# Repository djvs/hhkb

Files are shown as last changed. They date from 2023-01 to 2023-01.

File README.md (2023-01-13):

# hhkb

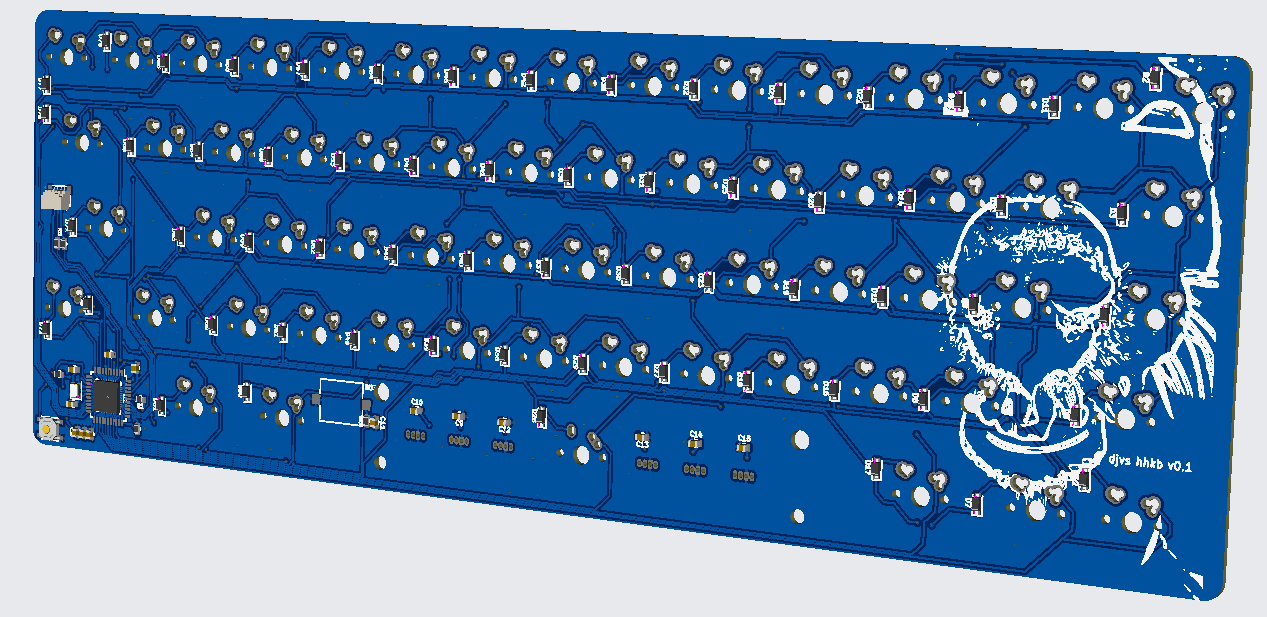
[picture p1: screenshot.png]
Screenshot of PCB


USB/QMK atmega32u4 pcb for HHKB with WS2812B addressable LED support and sonalert buzzer.  

Released without warranty, use at your own risk.  

PRs & feedback welcome!

---

Dimensions: 285 x 100 mm

---

Shield: [][cc-by-sa]

This work is licensed under a
[Creative Commons Attribution-ShareAlike 4.0 International License][cc-by-sa].

[][cc-by-sa]

[cc-by-sa]: http://creativecommons.org/licenses/by-sa/4.0/
[cc-by-sa-image]: https://licensebuttons.net/l/by-sa/4.0/88x31.png
[cc-by-sa-shield]: https://img.shields.io/badge/License-CC%20BY--SA%204.0-lightgrey.svg

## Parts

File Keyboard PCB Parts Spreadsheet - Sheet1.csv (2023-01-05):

Part Name | Part Type | Value | Footprint | Digikey Part Num. | LCSC Part Num. | JLCSMT Type | Other Notes
nSMD050-24V | PTC Resettable Fuse | 500mA | 1206 |  | C70076 | Extended
1206L050/15YR | Polyfuse | 500mA Hold / 1A Trip | 1206 |  | C151162 | Extended | The fuse listed in the tutorial doesn't appear to be available, but this one is.
0603WAF220JT5E | Resistor | 22 | 0603 |  | C23345 | Basic
0603WAF1001T5E | Resistor | 1k | 0603 |  | C21191 | Basic
0603WAF5101T5E | Resistor | 5.1k | 0603 |  | C23186 | Basic
0603WAF1002T5E | Resistor | 10k | 0603 |  | C25804 | Basic
0603WAF3302T5E | Resistor | 33k | 0603 |  | C4216 | Basic
0603WAF1003T5E | Resistor | 100k | 0603 |  | C25803 | Basic
0603WAF1004T5E | Resistor | 1M | 0603 |  | C22935 | Basic
CL10C220JB8NNNC | Capacitor, Ceramic | 22pF | 0603 |  | C1653 | Basic
0603B472K500NT | Capacitor, Ceramic | 4.7nF | 0603 |  | C53987 | Basic
CC0603KRX7R9BB104 | Capacitor, Ceramic | 0.1uF | 0603 |  | C14663 | Basic
CL10A105KB8NNNC | Capacitor, Ceramic | 1uF | 0603 |  | C15849 | Basic
CL10A475KO8NNNC | Capacitor, Ceramic | 4.7uF | 0603 |  | C19666 | Basic
CL10A106KP8NNNC | Capacitor, Ceramic | 10uF | 0603 |  | C19702 | Basic
CL10A226MQ8NRNC | Capacitor, Ceramic | 22uF | 0603 |  | C59461 | Basic
0603WAF4701T5E | Resistor | 4.7k | 0603 |  | C23162 | Basic
0805W8F220JT5E | Resistor | 22 | 0805 |  | C17561 | Basic
0805W8F1001T5E | Resistor | 1k | 0805 |  | C17513 | Basic
0805W8F5101T5E | Resistor | 5.1k | 0805 |  | C27834 | Basic
0805W8F1002T5E | Resistor | 10k | 0805 |  | C17414 | Basic
0805W8F3302T5E | Resistor | 33k | 0805 |  | C17633 | Basic
0805W8F1003T5E | Resistor | 100k | 0805 |  | C17407 | Basic
0805W8F1004T5E | Resistor | 1M | 0805 |  | C17514 | Basic
CL21C220JBANNNC | Capacitor, Ceramic | 22pF | 0805 |  | C1804 | Basic
0805B472K500NT | Capacitor, Ceramic | 4.7nF | 0805 |  | C1744 | Basic
CC0805KRX7R9BB104 | Capacitor, Ceramic | 0.1uF | 0805 |  | C49678 | Basic
CL21B105KBFNNNE | Capacitor, Ceramic | 1uF | 0805 |  | C28323 | Basic
CL21A475KAQNNNE | Capacitor, Ceramic | 4.7uF | 0805 |  | C1779 | Basic
CL21A106KAYNNNE | Capacitor, Ceramic | 10uF | 0805 |  | C15850 | Basic
CL21A226MAQNNNE | Capacitor, Ceramic | 22uF | 0805 |  | C45783 | Basic
0805W8F4701T5E | Resistor | 4.7k | 0805 |  | C17673 | Basic | Used by split boards w/ QMK
PJ-320A | TRRS Connector, 3.5mm, THT |  | 3.5-4P |  | --- | Unavailable | Many colors available on Taobao
ATMEGA32U2-AU | Microcontroller | AVR | 32-TQFP (7x7) | ATMEGA32U2-AU-ND | C618733 | Unavailable
ATMEGA32U2-MU | Microcontroller | AVR | 32-VQFN (5x5) | ATMEGA32U2-MU-ND | C57345 | Extended
X322516MLB4SI | Crystal Oscillator | 16MHz | 3225 |  | C13738 | Basic
TS-1186D-C-A | Push Button |  | 4.70mm x 3.50mm |  | C397351 | Unavailable | Side-actuated tactile switch
ATMEGA32U4-AU | Microcontroller | AVR | 44-TQFP (10x10) | ATMEGA32U4-AU-ND | C44854 | Extended
ATMEGA32U4-MU | Microcontroller | AVR | 44-VQFN (7x7) | ATMEGA32U4-MU-ND | C112161 | Extended
STM32F072CBT6 | Microcontroller | ARM/STM32 | 48-LQFP (7x7) | 497-14645-ND | C81720 | Extended
STM32F072CBU6 | Microcontroller | ARM/STM32 | 48-UFQFPN (7x7) | 497-14646-ND | C92504 | Extended
TS-1187A-B-A-B | Push Button |  | 5.1 x 5.1 MM |  | C318884 | Extended
TAJB107K006RNJ | Capacitor, Tantalum | 100uF | CASE-B / 3528 |  | C16133 | Basic
EC11K1525413 | Encoder |  | EC11E |  | C470752 | Unavailable | "Best" normal encoder with detents
EC11E1834403 | Encoder |  | EC11E |  | C361165 | Unavailable | Highest pulse EC11E w/o detents, 1.5mm switch
EC11E15244B2 | Encoder |  | EC11E |  |  | Unavailable | 30 detent (highest reliable) EC11E, 1.5mm switch
TYPE-C-31-M-12 | USB-C |  | HRO-TYPE-C-31-M-12 |  | C165948 | Unavailable | Cheap popular easy to solder USB 2.0 USB-C connector, even cheaper clones available in bulk from aliexpress at around 15c/each, shipped, https://www.aliexpress.com/item/4000259156096.html
TYPE-C-31-M-13 | USB-C |  | HRO-TYPE-C-31-M-13 |  | C223906 | Unavailable | mid-mount version of M-12
TYPE-C-31-M-14 | USB-C |  | HRO-TYPE-C-31-M-14 |  | C223907 | Unavailable | Mid mount version USB-C - Used on the unsplit
DY-S352818/RGBC/6812-2T | LED |  | SK6812 Mini-E |  | C524051 | Unavailable | Tested and seems to work same as a SK6812 Mini-E
SM4007PL | Diode, Standard |  | SOD-123 |  | C64898 | Basic | cheapest diode on jlcpcb, price fluctuates but <$0.004 (at 200+) each
1N4148W | Diode, Standard |  | SOD-123 |  | C81598 | Basic | Common diode
RB060M-60 | Schottky Barrier Diode |  | SOD-123 |  | C115330 | Extended
SMF9.0CA | Bidirectional TVS Diode | 9V Breakdown | SOD-123 |  | C123799 | Extended
SMF6.0CA | Bidirectional TVS Diode | 6V Breakdown | SOD-123 |  | C123791 | Extended
UET14A05L03 | ESD Protection IC |  | SOT-143 |  | C78442 | Extended | Equivalent to PRTR5V0U2X but available as extended part for assembly
PRTR5V0U2X,215 | ESD Protection IC |  | SOT-143B | 1727-3884-2-ND | C12333 | Unavailable | USB data line ESD protection
XC6206P332MR | LDO | 3.3V | SOT-23 |  | C5446 | Basic | 3.3v 200mA LDO stable with ceramic caps and basic JLC part https://datasheet.lcsc.com/szlcsc/1809201513_Torex-Semicon-XC6206P332MR_C5446.pdf
DTC123JKAT146 | Transistor, NPN, Pre-Biased | DTC123J | SOT-23 |  | C111724 | Extended
AO3400A | MOSFET, N-Channel | 30V 5.7A | SOT-23 |  | C347475 | Extended
BSS138LT1G | MOSFET, N-Channel | 50V 200mA | SOT-23 |  | C82045 | Extended | Often used for level shifting
AO3400A | MOSFET, N-Channel | 30V 5.7A | SOT-23-3L |  | C20917 | Basic
SRV05-4-P-T7 | ESD Protection IC | 4 I/Os | SOT-23-6 |  | C85364 | Basic | basic part esd protection for usb https://datasheet.lcsc.com/szlcsc/1809192313_ProTek-Devices-SRV05-4-P-T7_C85364.pdf

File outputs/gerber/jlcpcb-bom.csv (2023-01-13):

Comment | Footprint | Designator | JLCPCB Part #（optional )
D_Small | D_SOD-123 | D16,D2,D3,D4,D5,D7,D8,D9,D10,D11,D13,D14,D15,D17,D18,D19,D20,D21,D24,D25,D26,D27,D28,D29,D30,D31,D32,D35,D36,D37,D38,D39,D40,D41,D42,D46,D47,D48,D49,D50,D51,D52,D53,D54,D57,D58,D59,D60,D61,D62,D63,D64,D65,D68,D69,D70,D71,D72,D76,D77,D12 | C81598
0.1uF | C_0805_2012Metric | C9,C1,C2,C5,C10,C12,C11,C14,C15,C13 | C49678
330 | R_0805_2012Metric | R1 | C17630
SW_Push | SKQG-1155865 | SW1 | C318884
1uF | C_0805_2012Metric | C6 | C28323
10uF | C_0805_2012Metric | C7 | C15850
Conn_01x04_MountingPin | JST_SH_SM04B-SRSS-TB_1x04-1MP_P1.00mm_Horizontal | J1 | C160404
10k | R_0805_2012Metric | R3,R4 | C17414
ATmega32U4-MU | atmega32u4-mu-and-au | U1 | C112161
16MHz | Crystal_SMD_3225-4Pin_3.2x2.5mm | Y1 | C13738
22pF | C_0805_2012Metric | C3,C4 | C1804
22 | R_0805_2012Metric | R5,R2,R6 | C17561

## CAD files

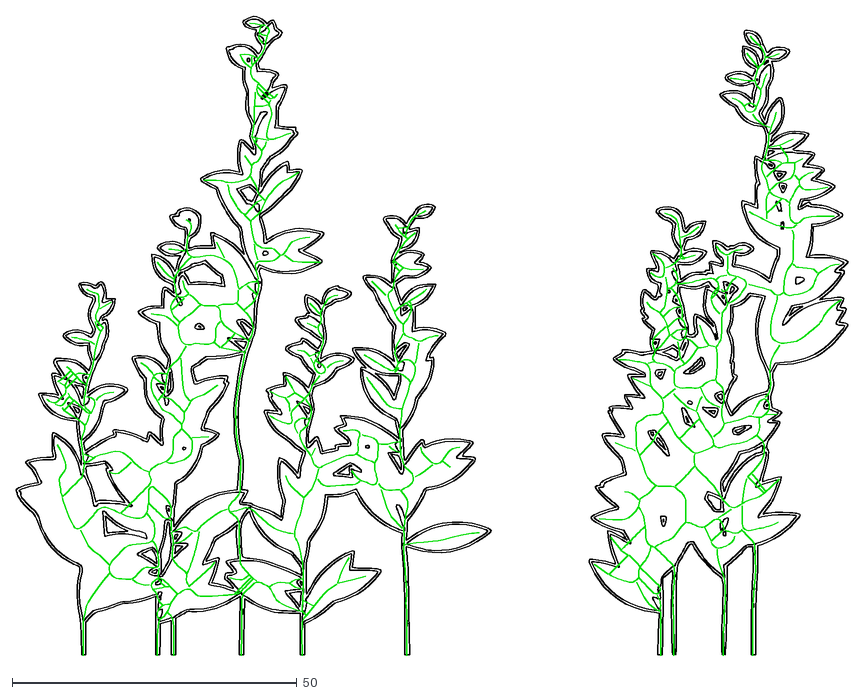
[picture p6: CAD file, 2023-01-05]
drawing.dxf
146.1 x 112.3

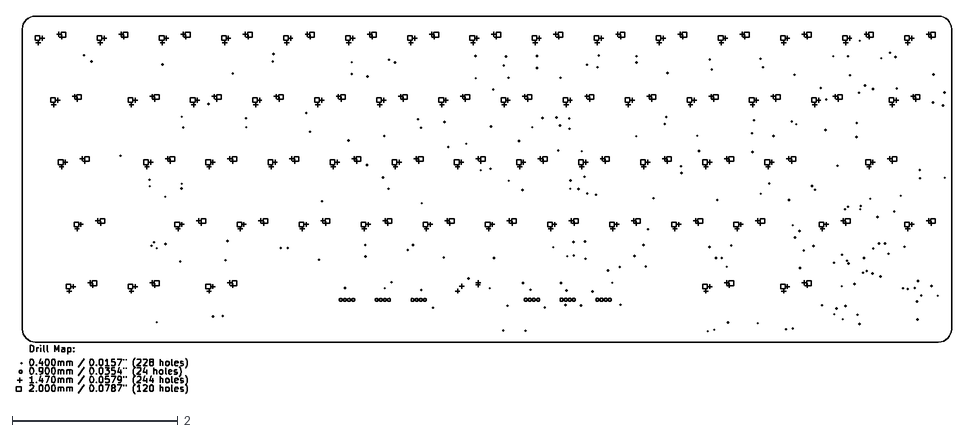
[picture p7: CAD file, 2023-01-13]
outputs/gerber/hhkb-PTH-drl_map.dxf
11.3 x 4.56

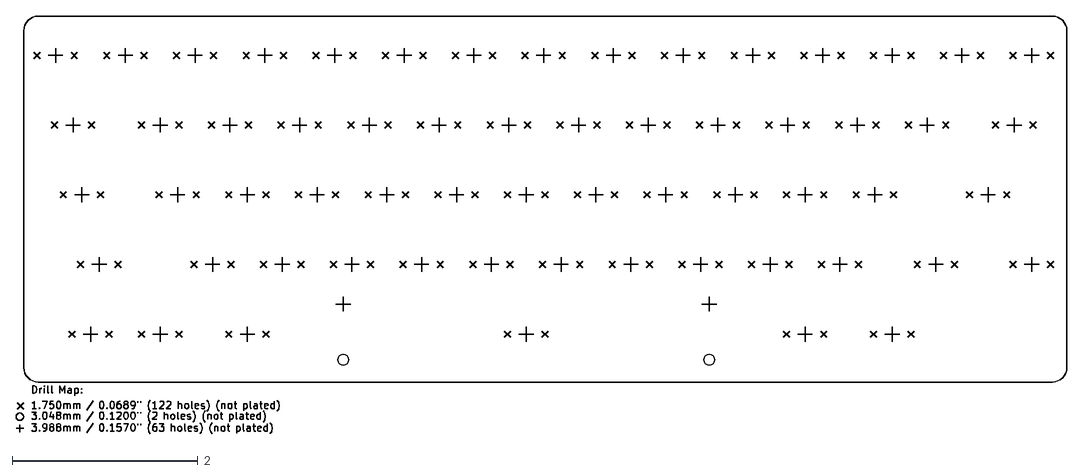
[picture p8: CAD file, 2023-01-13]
outputs/gerber/hhkb-NPTH-drl_map.dxf
11.3 x 4.49

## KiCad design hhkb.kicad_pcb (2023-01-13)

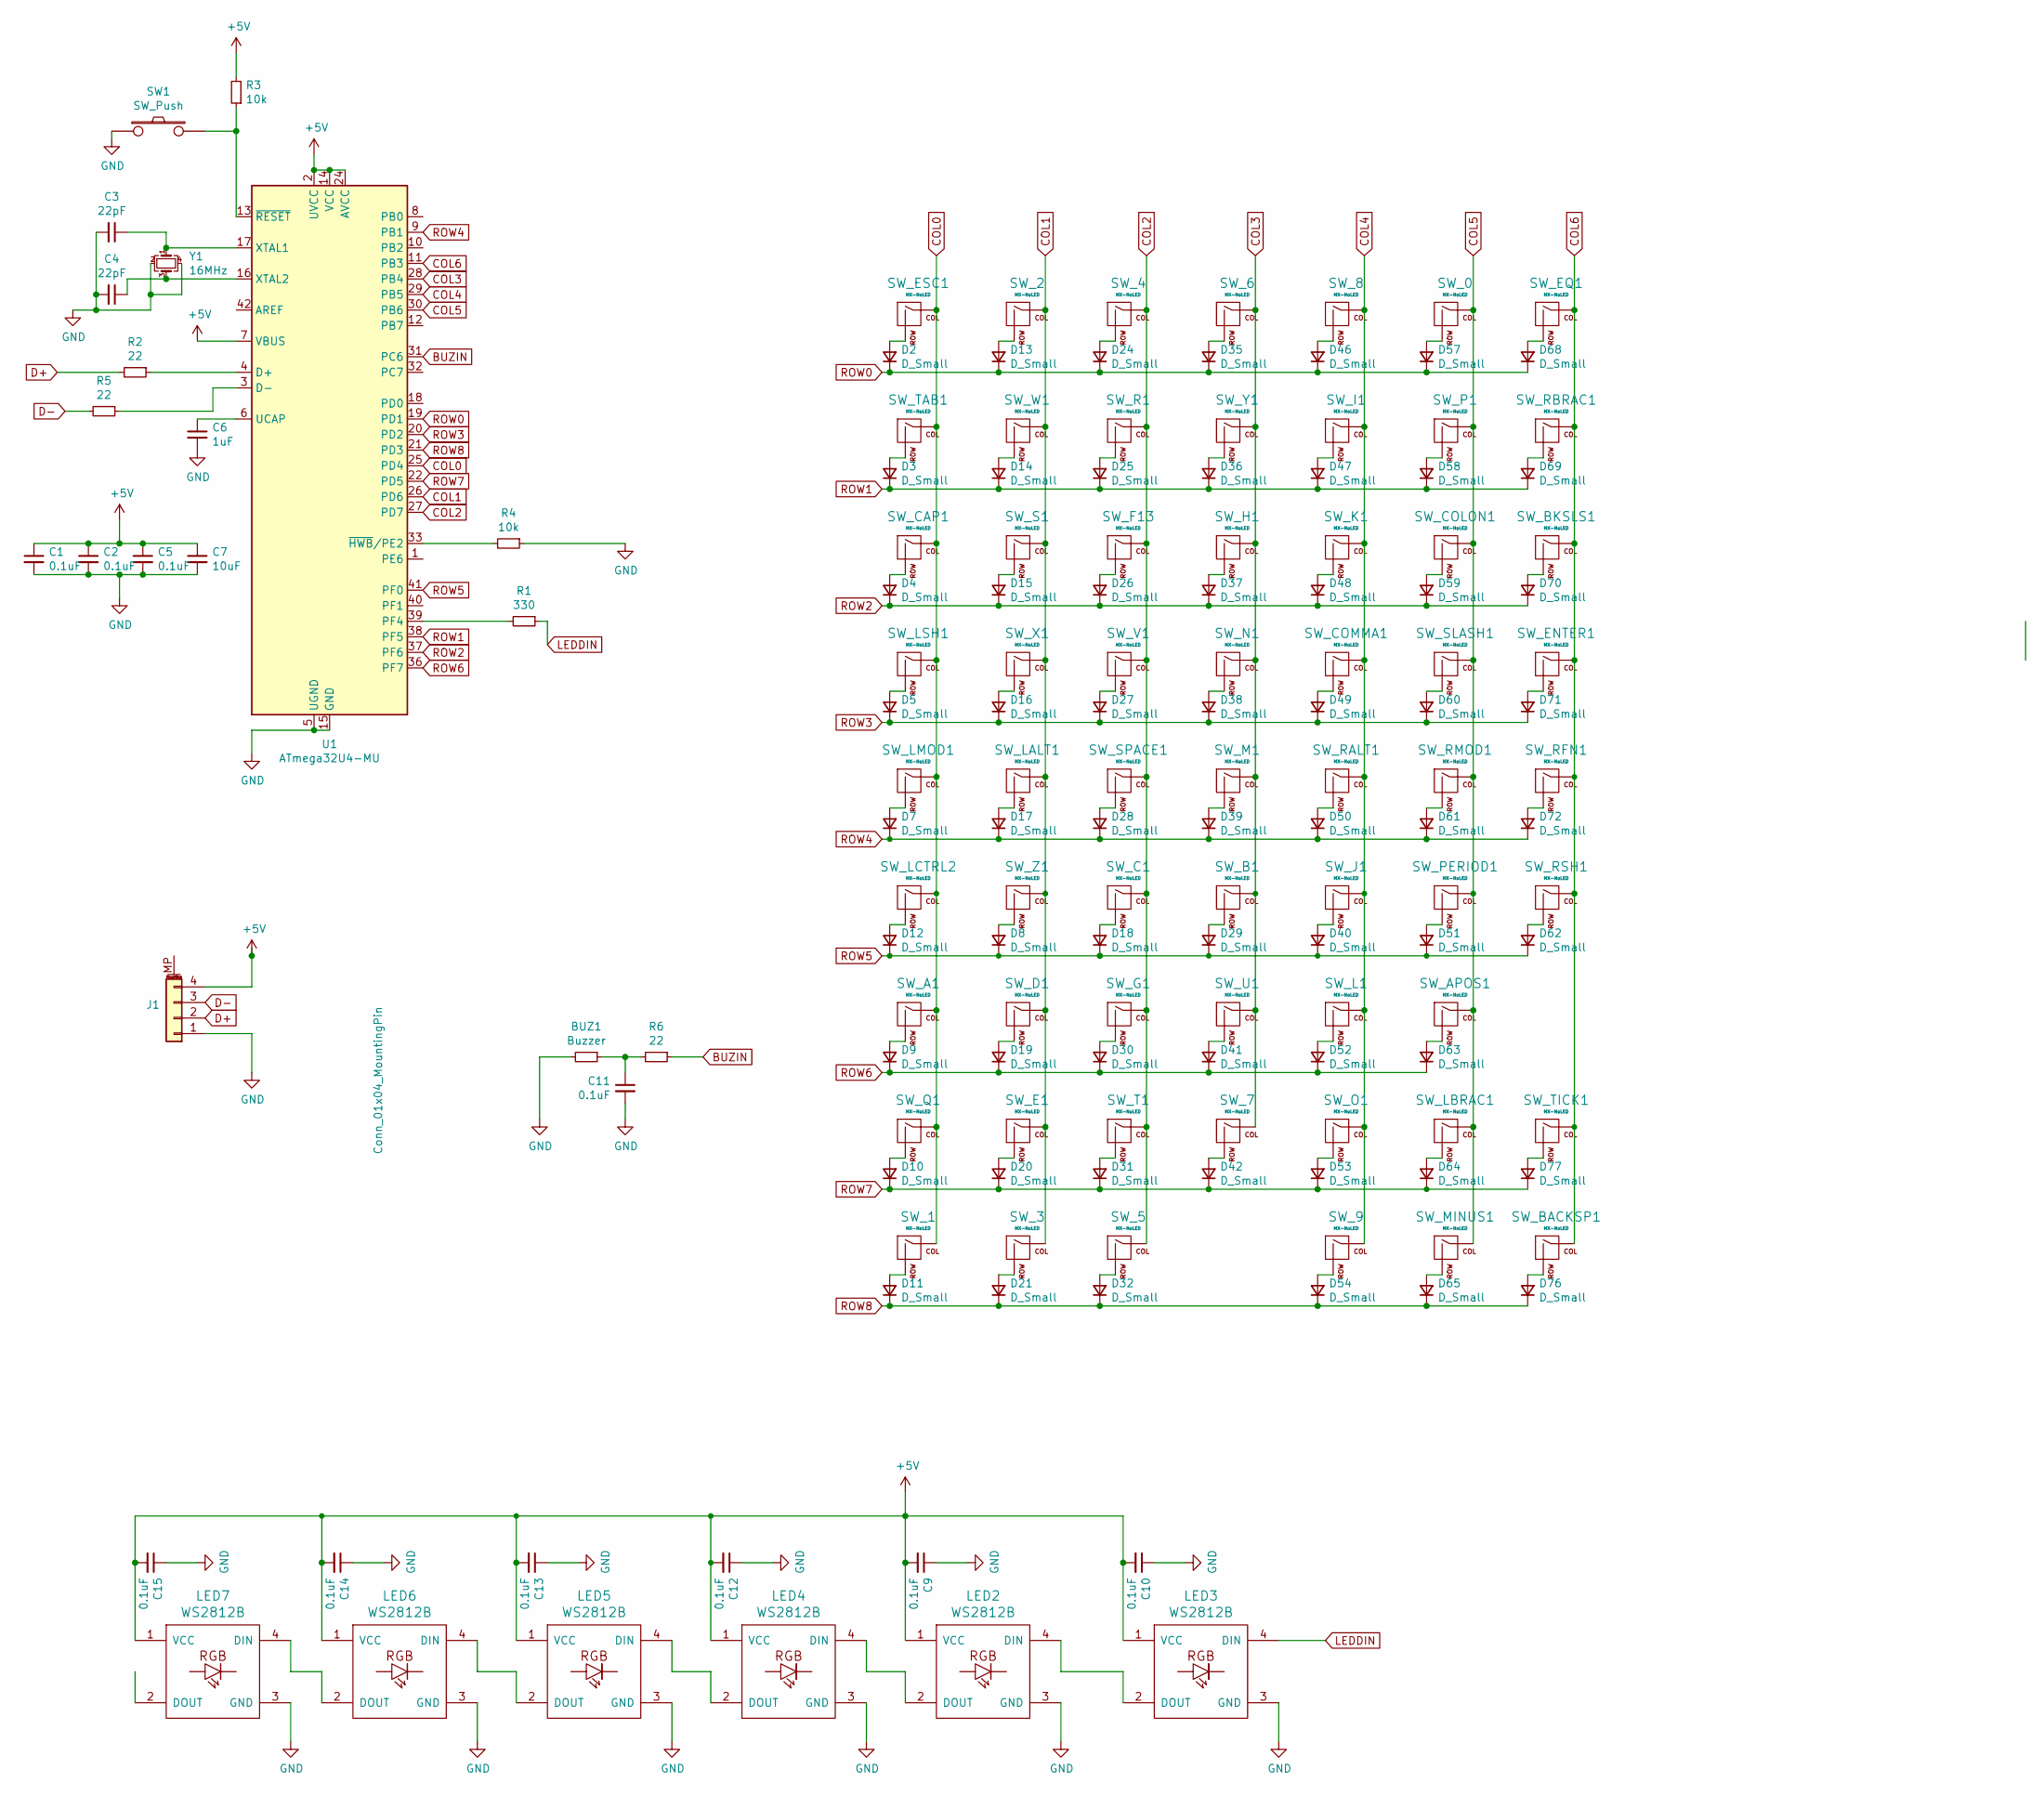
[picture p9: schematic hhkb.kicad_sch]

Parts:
BUZ1: Buzzer; Buzzer_Mallory_AST1109MLTRQ
C1, C2, C5, C9, C10, C11, C12, C13, C14, C15: 0.1uF; C_0805_2012Metric
C3, C4: 22pF; C_0805_2012Metric
C6: 1uF; C_0805_2012Metric
C7: 10uF; C_0805_2012Metric
D2, D3, D4, D5, D7, D8, D9, D10, D11, D12, D13, D14, D15, D16, D17, D18, D19, D20, D21, D24, D25, D26, D27, D28, D29, D30, D31, D32, D35, D36, D37, D38, D39, D40, D41, D42, D46, D47, D48, D49, D50, D51, D52, D53, D54, D57, D58, D59, D60, D61, D62, D63, D64, D65, D68, D69, D70, D71, D72, D76, D77: D_Small; D_SOD-123
J1: Conn_01x04_MountingPin; JST_SH_SM04B-SRSS-TB_1x04-1MP_P1.00mm_Horizontal
LED2, LED3, LED4, LED5, LED6, LED7: WS2812B; WS2812BDual
R1: 330; R_0805_2012Metric
R2, R5, R6: 22; R_0805_2012Metric
R3, R4: 10k; R_0805_2012Metric
SW1: SW_Push; SKQG-1155865
SW_0, SW_1, SW_2, SW_3, SW_4, SW_5, SW_6, SW_7, SW_8, SW_9: MX-NoLED; mx-nec-alps
SW_A1: MX-NoLED; mx-nec-alps
SW_APOS1: MX-NoLED; mx-nec-alps
SW_B1: MX-NoLED; mx-nec-alps
SW_BACKSP1: MX-NoLED; mx-nec-alps
SW_BKSLS1: MX-NoLED; mx-nec-alps
SW_C1: MX-NoLED; mx-nec-alps
SW_CAP1: MX-NoLED; mx-nec-alps
SW_COLON1: MX-NoLED; mx-nec-alps
SW_COMMA1: MX-NoLED; mx-nec-alps
SW_D1: MX-NoLED; mx-nec-alps
SW_E1: MX-NoLED; mx-nec-alps
SW_ENTER1: MX-NoLED; mx-nec-alps
SW_EQ1: MX-NoLED; mx-nec-alps
SW_ESC1: MX-NoLED; mx-nec-alps
SW_F13: MX-NoLED; mx-nec-alps
SW_G1: MX-NoLED; mx-nec-alps
SW_H1: MX-NoLED; mx-nec-alps
SW_I1: MX-NoLED; mx-nec-alps
SW_J1: MX-NoLED; mx-nec-alps
SW_K1: MX-NoLED; mx-nec-alps
SW_L1: MX-NoLED; mx-nec-alps
SW_LALT1: MX-NoLED; mx-nec-alps
SW_LBRAC1: MX-NoLED; mx-nec-alps
SW_LCTRL2: MX-NoLED; mx-nec-alps
SW_LMOD1: MX-NoLED; mx-nec-alps
SW_LSH1: MX-NoLED; mx-nec-alps
SW_M1: MX-NoLED; mx-nec-alps
SW_MINUS1: MX-NoLED; mx-nec-alps
SW_N1: MX-NoLED; mx-nec-alps
SW_O1: MX-NoLED; mx-nec-alps
SW_P1: MX-NoLED; mx-nec-alps
SW_PERIOD1: MX-NoLED; mx-nec-alps
SW_Q1: MX-NoLED; mx-nec-alps
SW_R1: MX-NoLED; mx-nec-alps
SW_RALT1: MX-NoLED; mx-nec-alps
SW_RBRAC1: MX-NoLED; mx-nec-alps
SW_RFN1: MX-NoLED; mx-nec-alps
SW_RMOD1: MX-NoLED; mx-nec-alps
SW_RSH1: MX-NoLED; mx-nec-alps
SW_S1: MX-NoLED; mx-nec-alps
SW_SLASH1: MX-NoLED; mx-nec-alps
SW_SPACE1: MX-NoLED; MX-6.5U-ReversedStabilizers-NoLED
SW_T1: MX-NoLED; mx-nec-alps
SW_TAB1: MX-NoLED; mx-nec-alps
SW_TICK1: MX-NoLED; mx-nec-alps
SW_U1: MX-NoLED; mx-nec-alps
SW_V1: MX-NoLED; mx-nec-alps
SW_W1: MX-NoLED; mx-nec-alps
SW_X1: MX-NoLED; mx-nec-alps
SW_Y1: MX-NoLED; mx-nec-alps
SW_Z1: MX-NoLED; mx-nec-alps
U1: ATmega32U4-MU; atmega32u4-mu-and-au
Y1: 16MHz; Crystal_SMD_3225-4Pin_3.2x2.5mm

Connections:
+5V: C1.1, C2.1, C5.1, C7.1, C9.2, C10.2, C12.2, C13.2, C14.2, C15.2, J1.4, LED2.1 (VCC), LED3.1 (VCC), LED4.1 (VCC), LED5.1 (VCC), LED6.1 (VCC), LED7.1 (VCC), R3.2, U1.2 (UVCC), U1.7 (VBUS), U1.14 (VCC), U1.24 (AVCC), U1.34 (VCC), U1.44 (AVCC)
BUZIN: R6.1, U1.31 (PC6)
COL0: SW_1.1 (COL), SW_A1.1 (COL), SW_CAP1.1 (COL), SW_ESC1.1 (COL), SW_LCTRL2.1 (COL), SW_LMOD1.1 (COL), SW_LSH1.1 (COL), SW_Q1.1 (COL), SW_TAB1.1 (COL), U1.25 (PD4)
COL1: SW_2.1 (COL), SW_3.1 (COL), SW_D1.1 (COL), SW_E1.1 (COL), SW_LALT1.1 (COL), SW_S1.1 (COL), SW_W1.1 (COL), SW_X1.1 (COL), SW_Z1.1 (COL), U1.26 (PD6)
COL2: SW_4.1 (COL), SW_5.1 (COL), SW_C1.1 (COL), SW_F13.1 (COL), SW_G1.1 (COL), SW_R1.1 (COL), SW_SPACE1.1 (COL), SW_T1.1 (COL), SW_V1.1 (COL), U1.27 (PD7)
COL3: SW_6.1 (COL), SW_7.1 (COL), SW_B1.1 (COL), SW_H1.1 (COL), SW_M1.1 (COL), SW_N1.1 (COL), SW_U1.1 (COL), SW_Y1.1 (COL), U1.28 (PB4)
COL4: SW_8.1 (COL), SW_9.1 (COL), SW_COMMA1.1 (COL), SW_I1.1 (COL), SW_J1.1 (COL), SW_K1.1 (COL), SW_L1.1 (COL), SW_O1.1 (COL), SW_RALT1.1 (COL), U1.29 (PB5)
COL5: SW_0.1 (COL), SW_APOS1.1 (COL), SW_COLON1.1 (COL), SW_LBRAC1.1 (COL), SW_MINUS1.1 (COL), SW_P1.1 (COL), SW_PERIOD1.1 (COL), SW_RMOD1.1 (COL), SW_SLASH1.1 (COL), U1.30 (PB6)
COL6: SW_BACKSP1.1 (COL), SW_BKSLS1.1 (COL), SW_ENTER1.1 (COL), SW_EQ1.1 (COL), SW_RBRAC1.1 (COL), SW_RFN1.1 (COL), SW_RSH1.1 (COL), SW_TICK1.1 (COL), U1.11 (PB3)
D+: J1.2, R2.2
D-: J1.3, R5.2
GND: BUZ1.2, C1.2, C2.2, C3.2, C4.2, C5.2, C6.2, C7.2, C9.1, C10.1, C11.2, C12.1, C13.1, C14.1, C15.1, J1.1, LED2.3 (GND), LED3.3 (GND), LED4.3 (GND), LED5.3 (GND), LED6.3 (GND), LED7.3 (GND), R4.1, SW1.1, U1.5 (UGND), U1.15 (GND), U1.23 (GND), U1.35 (GND), U1.43 (GND), U1.45 (GND), Y1.2, Y1.4
LEDDIN: LED3.4 (DIN), R1.1
unnamed: BUZ1.1, C11.1, R6.2
unnamed: D2.2 (A), SW_ESC1.2 (ROW)
unnamed: D3.2 (A), SW_TAB1.2 (ROW)
unnamed: D4.2 (A), SW_CAP1.2 (ROW)
unnamed: D5.2 (A), SW_LSH1.2 (ROW)
unnamed: D7.2 (A), SW_LMOD1.2 (ROW)
unnamed: D8.2 (A), SW_Z1.2 (ROW)
unnamed: D9.2 (A), SW_A1.2 (ROW)
unnamed: D10.2 (A), SW_Q1.2 (ROW)
unnamed: D11.2 (A), SW_1.2 (ROW)
unnamed: D12.2 (A), SW_LCTRL2.2 (ROW)
unnamed: D13.2 (A), SW_2.2 (ROW)
unnamed: D14.2 (A), SW_W1.2 (ROW)
unnamed: D15.2 (A), SW_S1.2 (ROW)
unnamed: D16.2 (A), SW_X1.2 (ROW)
unnamed: D17.2 (A), SW_LALT1.2 (ROW)
unnamed: D18.2 (A), SW_C1.2 (ROW)
unnamed: D19.2 (A), SW_D1.2 (ROW)
unnamed: D20.2 (A), SW_E1.2 (ROW)
unnamed: D21.2 (A), SW_3.2 (ROW)
unnamed: D24.2 (A), SW_4.2 (ROW)
unnamed: D25.2 (A), SW_R1.2 (ROW)
unnamed: D26.2 (A), SW_F13.2 (ROW)
unnamed: D27.2 (A), SW_V1.2 (ROW)
unnamed: D28.2 (A), SW_SPACE1.2 (ROW)
unnamed: D29.2 (A), SW_B1.2 (ROW)
unnamed: D30.2 (A), SW_G1.2 (ROW)
unnamed: D31.2 (A), SW_T1.2 (ROW)
unnamed: D32.2 (A), SW_5.2 (ROW)
unnamed: D35.2 (A), SW_6.2 (ROW)
unnamed: D36.2 (A), SW_Y1.2 (ROW)
unnamed: D37.2 (A), SW_H1.2 (ROW)
unnamed: D38.2 (A), SW_N1.2 (ROW)
unnamed: D39.2 (A), SW_M1.2 (ROW)
unnamed: D40.2 (A), SW_J1.2 (ROW)
unnamed: D41.2 (A), SW_U1.2 (ROW)
unnamed: D42.2 (A), SW_7.2 (ROW)
unnamed: D46.2 (A), SW_8.2 (ROW)
unnamed: D47.2 (A), SW_I1.2 (ROW)
unnamed: D48.2 (A), SW_K1.2 (ROW)
unnamed: D49.2 (A), SW_COMMA1.2 (ROW)
unnamed: D50.2 (A), SW_RALT1.2 (ROW)
unnamed: D51.2 (A), SW_PERIOD1.2 (ROW)
unnamed: D52.2 (A), SW_L1.2 (ROW)
unnamed: D53.2 (A), SW_O1.2 (ROW)
unnamed: D54.2 (A), SW_9.2 (ROW)
unnamed: D57.2 (A), SW_0.2 (ROW)
unnamed: D58.2 (A), SW_P1.2 (ROW)
unnamed: D59.2 (A), SW_COLON1.2 (ROW)
unnamed: D60.2 (A), SW_SLASH1.2 (ROW)
unnamed: D61.2 (A), SW_RMOD1.2 (ROW)
unnamed: D62.2 (A), SW_RSH1.2 (ROW)
unnamed: D63.2 (A), SW_APOS1.2 (ROW)
unnamed: D64.2 (A), SW_LBRAC1.2 (ROW)
unnamed: D65.2 (A), SW_MINUS1.2 (ROW)
unnamed: D68.2 (A), SW_EQ1.2 (ROW)
unnamed: D69.2 (A), SW_RBRAC1.2 (ROW)
unnamed: D70.2 (A), SW_BKSLS1.2 (ROW)
unnamed: D71.2 (A), SW_ENTER1.2 (ROW)
unnamed: D72.2 (A), SW_RFN1.2 (ROW)
unnamed: D76.2 (A), SW_BACKSP1.2 (ROW)
unnamed: D77.2 (A), SW_TICK1.2 (ROW)
unnamed: LED2.4 (DIN), LED3.2 (DOUT)
unnamed: LED2.2 (DOUT), LED4.4 (DIN)
unnamed: LED4.2 (DOUT), LED5.4 (DIN)
unnamed: LED5.2 (DOUT), LED6.4 (DIN)
unnamed: LED6.2 (DOUT), LED7.4 (DIN)
unnamed: R2.1, U1.4 (D+)
unnamed: R5.1, U1.3 (D-)
unnamed: R1.2, U1.39 (PF4)
unnamed: C6.1, U1.6 (UCAP)
unnamed: C3.1, U1.17 (XTAL1), Y1.1
unnamed: C4.1, U1.16 (XTAL2), Y1.3
unnamed: R4.2, U1.33 (~HWB/PE2)
unnamed: R3.1, SW1.2, U1.13 (~RESET)
ROW0: D2.1 (K), D13.1 (K), D24.1 (K), D35.1 (K), D46.1 (K), D57.1 (K), D68.1 (K), U1.19 (PD1)
ROW1: D3.1 (K), D14.1 (K), D25.1 (K), D36.1 (K), D47.1 (K), D58.1 (K), D69.1 (K), U1.38 (PF5)
ROW2: D4.1 (K), D15.1 (K), D26.1 (K), D37.1 (K), D48.1 (K), D59.1 (K), D70.1 (K), U1.37 (PF6)
ROW3: D5.1 (K), D16.1 (K), D27.1 (K), D38.1 (K), D49.1 (K), D60.1 (K), D71.1 (K), U1.20 (PD2)
ROW4: D7.1 (K), D17.1 (K), D28.1 (K), D39.1 (K), D50.1 (K), D61.1 (K), D72.1 (K), U1.9 (PB1)
ROW5: D8.1 (K), D12.1 (K), D18.1 (K), D29.1 (K), D40.1 (K), D51.1 (K), D62.1 (K), U1.41 (PF0)
ROW6: D9.1 (K), D19.1 (K), D30.1 (K), D41.1 (K), D52.1 (K), D63.1 (K), U1.36 (PF7)
ROW7: D10.1 (K), D20.1 (K), D31.1 (K), D42.1 (K), D53.1 (K), D64.1 (K), D77.1 (K), U1.22 (PD5)
ROW8: D11.1 (K), D21.1 (K), D32.1 (K), D54.1 (K), D65.1 (K), D76.1 (K), U1.21 (PD3)

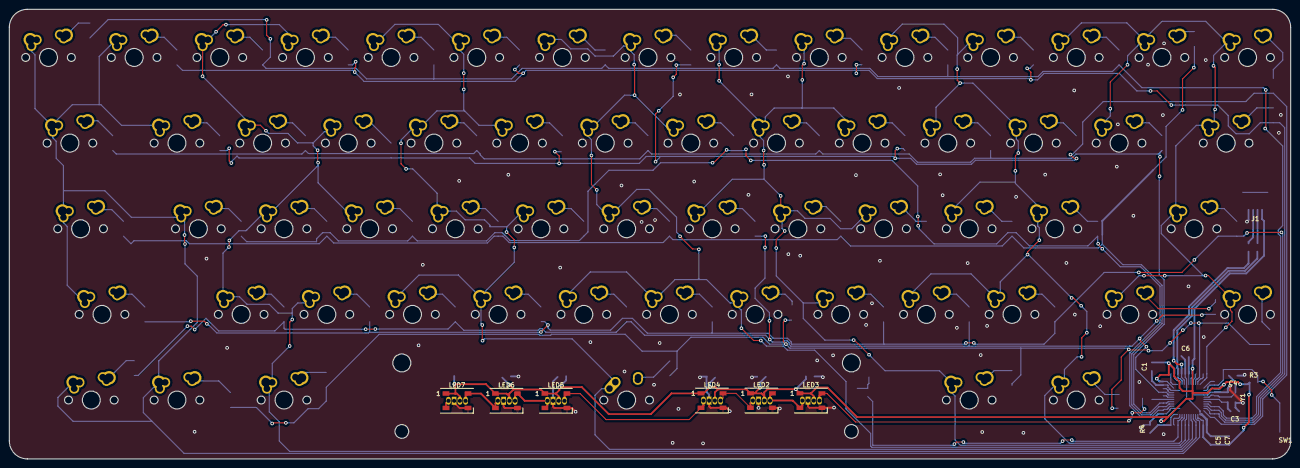
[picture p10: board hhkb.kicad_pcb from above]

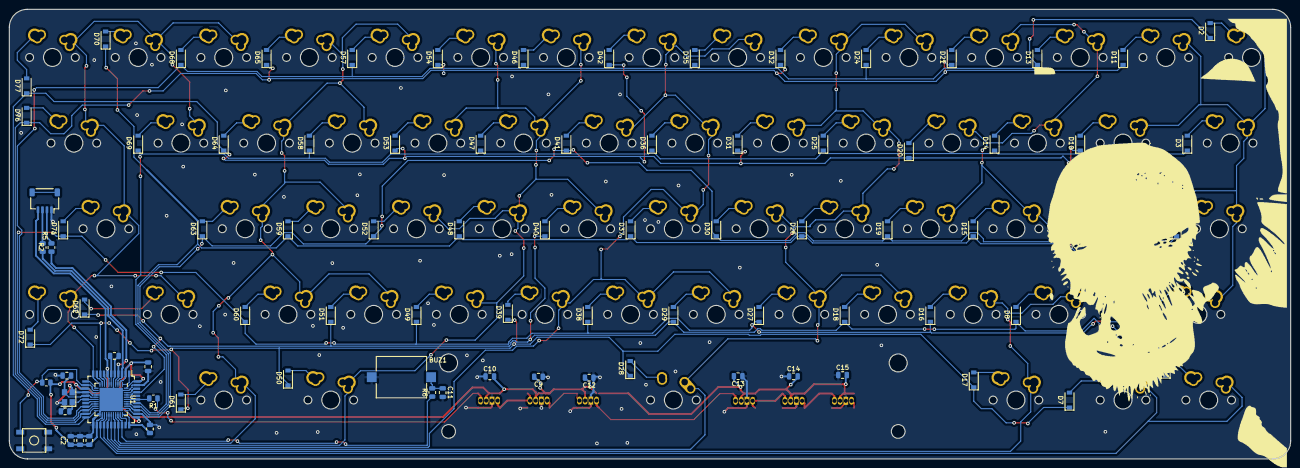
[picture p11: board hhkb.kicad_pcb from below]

Board: 2 copper layers, 285.0 x 100.0 mm, 153 parts (86 on the bottom side), 97 nets.

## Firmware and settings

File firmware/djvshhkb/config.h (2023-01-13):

/*
Copyright 2021 djvs

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
You should have received a copy of the GNU General Public License
along with this program.  If not, see <http://www.gnu.org/licenses/>.
*/

#pragma once

#include "config_common.h"

/* USB Device descriptor parameter */
#define VENDOR_ID    0x1209
#define PRODUCT_ID   0x9209
#define DEVICE_VER   0x0001
#define MANUFACTURER "djvs"
#define PRODUCT      "djvshhkb"

/* key matrix size */
#define MATRIX_ROWS 9
#define MATRIX_COLS 7
#define RGBLIGHT_LAYERS

/*
 * Keyboard Matrix Assignments
 *
 * Change this to how you wired your keyboard
 * COLS: AVR pins used for columns, left to right
 * ROWS: AVR pins used for rows, top to bottom
 * DIODE_DIRECTION: COL2ROW = COL = Anode (+), ROW = Cathode (-, marked on diode)
 *                  ROW2COL = ROW = Anode (+), COL = Cathode (-, marked on diode)
 *
 */
#define MATRIX_ROW_PINS { D1, F5, F6, D2, B1, F0, F7, D5, D3 }
#define MATRIX_COL_PINS { D4, D6, D7, B4, B5, B6, B3 }

/* COL2ROW, ROW2COL */
#define DIODE_DIRECTION COL2ROW

/*
 * Split Keyboard specific options, make sure you have 'SPLIT_KEYBOARD = yes' in your rules.mk, and define SOFT_SERIAL_PIN.
 */
// #define SOFT_SERIAL_PIN D0  // or D1, D2, D3, E6

//#define LED_NUM_LOCK_PIN B0
//#define LED_CAPS_LOCK_PIN B1
//#define LED_SCROLL_LOCK_PIN B2
//#define LED_COMPOSE_PIN B3
//#define LED_KANA_PIN B4

//#define BACKLIGHT_PIN F4
//#define BACKLIGHT_CAPS_LOCK
//#define BACKLIGHT_DRIVER = 
//#define BACKLIGHT_LEVELS 3
//#define BACKLIGHT_BREATHING

#define RGB_DI_PIN F4
#ifdef RGB_DI_PIN
#    define RGBLED_NUM 6
#    define RGBLIGHT_DEFAULT_MODE (RGBLIGHT_MODE_RAINBOW_SWIRL)

#    define RGBLIGHT_DEFAULT_HUE 64
//#    define RGBLIGHT_DEFAULT_SAT 255
#    define RGBLIGHT_DEFAULT_VAL 255
//#    define RGBLIGHT_HUE_STEP 8
//#    define RGBLIGHT_SAT_STEP 8
//#    define RGBLIGHT_VAL_STEP 8
//#    define RGBLIGHT_LIMIT_VAL 255 /* The maximum brightness level */
//#    define RGBLIGHT_SLEEP  /* If defined, the RGB lighting will be switched off when the host goes to sleep */
/*== all animations enable ==*/
#    define RGBLIGHT_ANIMATIONS
/*== or choose animations ==*/
//#    define RGBLIGHT_EFFECT_BREATHING
//#    define RGBLIGHT_EFFECT_RAINBOW_MOOD
//#    define RGBLIGHT_EFFECT_RAINBOW_SWIRL
//#    define RGBLIGHT_EFFECT_SNAKE
//
//#    define RGBLIGHT_EFFECT_KNIGHT
//#    define RGBLIGHT_EFFECT_CHRISTMAS
//#    define RGBLIGHT_EFFECT_STATIC_GRADIENT
//#    define RGBLIGHT_EFFECT_RGB_TEST
//#    define RGBLIGHT_EFFECT_ALTERNATING
/*== customize breathing effect ==*/
/*==== (DEFAULT) use fixed table instead of exp() and sin() ====*/
//#    define RGBLIGHT_BREATHE_TABLE_SIZE 256      // 256(default) or 128 or 64
/*==== use exp() and sin() ====*/
//#    define RGBLIGHT_EFFECT_BREATHE_CENTER 1.85  // 1 to 2.7
//#    define RGBLIGHT_EFFECT_BREATHE_MAX    255   // 0 to 255
#endif

/* Debounce reduces chatter (unintended double-presses) - set 0 if debouncing is not needed */
#define DEBOUNCE 5

/* define if matrix has ghost (lacks anti-ghosting diodes) */
//#define MATRIX_HAS_GHOST

/* Mechanical locking support. Use KC_LCAP, KC_LNUM or KC_LSCR instead in keymap */
#define LOCKING_SUPPORT_ENABLE
/* Locking resynchronize hack */
#define LOCKING_RESYNC_ENABLE

/* If defined, GRAVE_ESC will always act as ESC when CTRL is held.
 * This is useful for the Windows task manager shortcut (ctrl+shift+esc).
 */
//#define GRAVE_ESC_CTRL_OVERRIDE

/*
 * Force NKRO
 *
 * Force NKRO (nKey Rollover) to be enabled by default, regardless of the saved
 * state in the bootmagic EEPROM settings. (Note that NKRO must be enabled in the
 * makefile for this to work.)
 *
 * If forced on, NKRO can be disabled via magic key (default = LShift+RShift+N)
 * until the next keyboard reset.
 *
 * NKRO may prevent your keystrokes from being detected in the BIOS, but it is
 * fully operational during normal computer usage.
 *
 * For a less heavy-handed approach, enable NKRO via magic key (LShift+RShift+N)
 * or via bootmagic (hold SPACE+N while plugging in the keyboard). Once set by
 * bootmagic, NKRO mode will always be enabled until it is toggled again during a
 * power-up.
 *
 */
//#define FORCE_NKRO

/*
 * Feature disable options
 *  These options are also useful to firmware size reduction.
 */

/* disable debug print */
//#define NO_DEBUG

/* disable print */
//#define NO_PRINT

/* disable action features */
//#define NO_ACTION_LAYER
//#define NO_ACTION_TAPPING
//#define NO_ACTION_ONESHOT

/* disable these deprecated features by default */
#define NO_ACTION_MACRO
#define NO_ACTION_FUNCTION

/* Bootmagic Lite key configuration */
//#define BOOTMAGIC_LITE_ROW 0
//#define BOOTMAGIC_LITE_COLUMN 0

#define DYNAMIC_KEYMAP_LAYER_COUNT 2

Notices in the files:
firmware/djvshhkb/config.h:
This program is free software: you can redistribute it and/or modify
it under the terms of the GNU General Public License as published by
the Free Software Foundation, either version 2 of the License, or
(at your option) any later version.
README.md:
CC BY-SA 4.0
